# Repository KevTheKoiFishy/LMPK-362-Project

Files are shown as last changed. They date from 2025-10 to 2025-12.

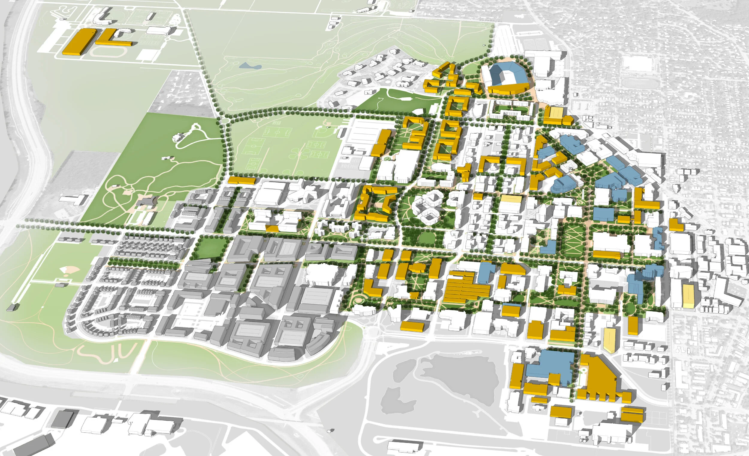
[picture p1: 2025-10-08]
media/images/Purdue_Map.jpg

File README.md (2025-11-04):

# LPMK ECE 362 Final Project
#### GPS Timekeeping and Alarm with Music on RP2350

### Parts List
- RP2350 Proton Board and Debugger
- <span style="color: #777">~~DS Series RTC (I<sup>2</sup>C)~~ (Rejected)</span>
- NEO-6M GPS Module (UART) for Satellite Timekeeping
- LCD TFT Display (SPI) with SD Card Reader (SPI) for Image Storage/Display + Audio Storage
- External DAC (I2C or Custom Build with Shift-Reg) for Audio Playback
- Passive Button Array Keypad for Navigation

### Functions
- Current Time
- GPS Map
- Alarm Settings
- Stopwatch
- Timer

### Project Tasks
1. Define Objectives
    - Get GTA approval
    - Agree on design
    - Assign roles
    - Who should keep the design?
    - Agree on meeting / build times
2. High-level planning
    - Hardware Diagram
    - Software Interface Diagram
3. Detailed Hardware Design
    - Determine pin allocation via GPIO needs
    - Determine required bus speeds via part datasheets
    - Design custom peripherals (ie. DAC)
4. Hardware Prototype
    - Breadboard Build
    - Electrical Verification
5. Software Build
    - Hardware Peripheral Backends
        - Create high-level functions for controlling peripherals easily (like in `display.c`)
        - A way to communicate with frontend
    - Application Frontend
        - Interface and Transition Logic
        - Graphics and UX Design
6. Iterate and Debug
7. PCB Build (if time available)
8. Report / Presentations

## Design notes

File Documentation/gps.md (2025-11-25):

Sample Boot Sequence
```
$GPTXT,01,01,02,MA=CASIC*27
$GPTXT,01,01,02,HW=ATGM332D,0009111648291*12
$GPTXT,01,01,02,IC=AT6558-5N-71-0C510800,J9K11CL-A4-013062*26
$GPTXT,01,01,02,SW=URANUS5,V5.2.1.0*1D
$GPTXT,01,01,02,TB=2019-08-12,10:01:41*4E
$GPTXT,01,01,02,MO=GBR*25
$GPTXT,01,01,02,BS=SOC_BootLoader,V6.2.0.2*34
$GPTXT,01,01,02,FI=00EF4014*7D
```

Sample 1s Push, No Satellites in view
```
$GNGGA,,,,,,0,00,25.5,,,,,,*64
$GNGLL,,,,,,V,M*79
$GPGSA,A,1,,,,,,,,,,,,,25.5,25.5,25.5*02
$BDGSA,A,1,,,,,,,,,,,,,25.5,25.5,25.5*13
$GLGSA,A,1,,,,,,,,,,,,,25.5,25.5,25.5*1E
$GPGSV,1,1,00*79
$BDGSV,1,1,00*68
$GLGSV,1,1,00*65
$GNRMC,,V,,,,,,,,,,M*4E
$GNVTG,,,,,,,,,M*2D
$GNZDA,,,,,,*56
$GPTXT,01,01,01,ANTENNA OK*35
```

Sample push, few satellites in view, only time available
```
$GNGGA,224452.000,,,,,0,00,25.5,,,,,,*7D
$GNGLL,,,,,224452.000,V,M*60
$GPGSA,A,1,,,,,,,,,,,,,25.5,25.5,25.5*02
$BDGSA,A,1,,,,,,,,,,,,,25.5,25.5,25.5*13
$GLGSA,A,1,,,,,,,,,,,,,25.5,25.5,25.5*1E
$GPGSV,1,1,04,13,,,27,17,,,32,19,,,24,22,,,31*71
$BDGSV,1,1,00*68
$GLGSV,1,1,00*65
$GNRMC,224452.000,V,,,,,,,,,,M*57
$GNVTG,,,,,,,,,M*2D
$GNZDA,224452.000,,,,,*4F
$GPTXT,01,01,01,ANTENNA OK*35
```

Sample push, many satellites in view, date and time available
```
$GNGGA,062157.000,,,,,0,00,4.5,,,,,,*4E
$GNGLL,,,,,062157.000,V,N*63
$GPGSA,A,1,,,,,,,,,,,,,7.0,4.5,5.3*30
$BDGSA,A,1,,,,,,,,,,,,,7.0,4.5,5.3*21
$GLGSA,A,1,,,,,,,,,,,,,7.0,4.5,5.3*2C
$GPGSV,3,1,09,05,83,243,,06,08,086,,12,21,206,16,13,21,148,*76
$GPGSV,3,2,09,18,05,278,,20,60,045,,21,61,050,,25,29,243,19*75
$GPGSV,3,3,09,29,52,309,23*47
$BDGSV,1,1,01,34,72,329,*53
$GLGSV,1,1,03,66,47,158,,65,57,065,,88,53,068,*53
$GNRMC,062157.000,V,,,,,,,251125,,,N*54
$GNVTG,,,,,,,,,N*2E
$GNZDA,062157.000,25,11,2025,00,00*4D
$GPTXT,01,01,01,ANTENNA OK*35
```

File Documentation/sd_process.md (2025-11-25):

After over 20 hours of this I finally made… basically a very crude iPod! In case anyone else needs help getting this to work, I want to leave some notes about what worked and what didn’t. The actual implementation and design choices are up to you!

## Setup
### Audio Output Choice

For starters, my approach is using PWM to play audio. This is because if I drive one pin when the wave is positive and another when the wave is negative, with the duty cycles proportional to abs(wave), then I can input those two PWMs to an H-bridge and double the RMS voltage… four times the audio power!

Back To The Future (Opening Guitar Amp Scene) - COMPLETE SOUND REPLACEMENT on Make a GIF

In hindsight, it would have made much more sense to use a DAC… but whatever, I’ve already sent the PCB in. 🤷🏻‍♀️

### File Format Choice

Now I had to choose the file format: **WAV or MP3?** The trade off is WAVs need higher memory bandwidth for their lossless playback, but MP3s need more compute for decoding. As long as `memory-copy time + decoding time < sampling period`, **it really don’t matter.**

HOWEVER. After looking into how to decode MP3s (`Huffman decoding -> inverse cosine transform -> multiply-accumulate`) I thought I should start with WAV for debuggability and sanity reasons. I ended up getting a **memcpy time : playback time** of only 1/8 at 32 KSPS, and this is pretty good.

I chose to use WAV formats with 16 bit-depth, mono channel, and PCM encoding. This just means that after the file header, the audio samples are stored sequentially as little-endian signed `int16_t`s. For each sample, I

1.  get the sample rate from the file header,
2.  set the pwm period to as close as `1 / sample_rate` as possible,
3.  and then update the pwm period to the next sample on each wrap (Lab 5 ts).

For a 44.1kHz audio, the standard sample rate, this means the prescaler is 1 and the top is `(3401 - 1)`. This also means I scale my `[-32768, 32767]` audio sample by `3401.0 / 32767.0` (0 - 100% duty) for each side of the H-bridge. While it’s an 8x reduction in actual precision, it’s only 3 of the 16 bits, which means the precision loss you hear only reduces by 20%.

> _In general_, for any rate exceeding `floor(F_CLK / (1 << bit_depth))`, increasing sample rate reduces bit depth. (This value sits at `2,288` samp/sec for `int16_t`) **This is the main disadvantage of the PWM approach VS a DAC + Class D amp, which achieves the same result with some noise.**



You can use \[online converters\] (https://www.freeconvert.com/mp3-to-wav) to change the bitrate, bit depth, etc. to fit your hardware constraints. I found that my setup works well at **32kHz, 16bit, mono**. After that, it tends to trip over itself - ie. there’s a small chance the memcpy doesn’t complete before the PWM ISR needs it, aka a buffer overrun.

### SPI clock speed

This one really tripped me up. You’d think that with a sample rate of 44.1 Khz, you’d need on the order of `8 bits / byte * 2 bytes / samp * 44.1e3 samp / sec`, so 1Mhz would cut it. However, this kept leading to buffer overruns, and I had to get it to 20Mhz to work. If anyone knows why, please enlighten me!

## Problems and Solutions
Development was not linear, I am but writing it so for presentability.

0. **CLOCK SPEED |** At first I could not get the sd card above 400kHz. I fixed this by writing 32 empty bytes with MOSI == HIGH after `sd_io_high_speed()` is called in `diskio.c` / `disk_initialize`. I just called `sdcard_init_clock();` 16 times. I’m also not sure why this works, but after adding it, I was able to get F\_sck all the way to 30Mhz.

<table><tbody><tr><td></td><td></td></tr></tbody></table>  
Yuhhh.
<br><br>

1. **AUDIO BUFFER |** The first thing I learned was that copying one sample at a time was slow; there’s overhead from going through calls stacks, loops, and accessing the file. When reading like this, the audio playback hardly kept up. I may not have perfect pitch, but it sounded worse than the piano next to WALC on a rainy day.  
On the other hand, reading chunks of 512-1024 bytes takes much less time per byte. So, instead of reading one sample from the file on each pwm-update-isr call, I created a circular FIFO buffer, tracking a read and write index. I raised a flag  in the ISR every time my buffer was 75% empty, and a function running in the main loop cleared the flag before filling it up. 

2. **COPY SIZE |** _HOWEVER_ beyond 1024 bytes at a time, I got hardware errors from FatFS, after which the SD card became inaccessible. If I wanted to consume more than 1024 bytes, I’d `f_read` multiple times, passing in an offset of the buffer each time.

3. **MULTICORE |** This is great, but now the SD read operation takes a good fraction of the buffer-playback time. So what? Well, that means the pwm-updating ISR will often interrupt the memcpy operation!  
SD cards are spoiled and become total princesses when it comes to timing, so this isn’t really ideal. (I’d often get glitches in audio when the memcpy operation gets thrown off).  
Besides, I wanted the main function to be busy doing other things, like – I don’t know – _rendering an entire display?!_ So I moved the poll-buffer-and-memcpy function to core 1, which got rid of most of the glitching.

4. **BUFFER SIZE |** I just tuned this one experimentally; 4096 and 8192 worked well. If you expect delays in reading from the SD, ie. from long wiring, give it more breathing space.

5. **DOUBLE BUFFERING |** Having the circular FIFO wasn't working really well, since the interrupt has to do a bunch of pointer math to figure out where to start and end copying, when to wrap around, etc. Which is DELAY. BAD. BOOO 👻.  
Therefore, I made a read (playback) buffer and write (memcpy) buffer, each 8192 in length (What was that? Oh, don't worry, the RP2350 has 512KB of space!) Now the memcpy function just has to fill up the write buffer from start to end, no wrap-arounds needed.
    - **The setup:**
        - Still have the PWM ISR read samples from the buffer and wrap around to 0 when it reaches the end.
        - Change the memcpy function to `0 -> buff_size` instead of `write index -> read index`.
        - Initialize a Buffer A, a Buffer B, a pointer to the read buffer, and a pointer to the write buffer. Assign one pointer to buffer A and the other to buffer B.
        - Initialize the memcpy flag to true.
        - Have the PWM ISR set the memcpy flag when the read index is at 0 rather than 75% of the way. Also, when read index is 0, swap the read and write buffer pointers.
    - **The process:**
        1. The memcpy flag is initialized to `true`, so as soon as the audio file opens and the `audio_file_open` flag is set, core1 fills the write buffer.
        2. When the read index reaches zero, the read and write buffers are swapped and the memcpy flag is set. Core0 plays what was initially written by Core1, while Core1 prepares the next buffer for Core0.
        3. The process repeats until the song is over, ie. when the file-offset pointer `&audio_file -> fptr` exceeds the filesize, which can be found in the WAV file header or by running `f_size(&audio_file)`.
<br><br>
6. **HARDWARE IMPROVEMENTS |** Even after all that, I was getting periodic glitching. I wasn't able to pinpoint what wasn't being copied using the debugger, and it would only happen sporadically. I thought the long wires between Pi and Display module might be the culprit, so I soldered the pins of a TF-to-SD adapter to short jumper wires and used that instead of the display SD slot. No problems so far.

## Results
Here's a before and after.
<table>
<tr>
<td> Before <b>(VOLUME WARNING)</b> </td> <td> During </td> <td> After </td>
</tr>
<tr>
<td>
<video height="300" controls>
  <source src="/redirect/s3?bucket=uploads&amp;prefix=paste%2Flj4sq92apfjja%2Fbab594b9123cea66a9ada61378599e2250a0d67be978048ed859affb52cb81f0%2FIMG_3299.mp4" type="video/mp4">
</video>
</td>
<td>
<video height="300" controls>
  <source src="/redirect/s3?bucket=uploads&amp;prefix=paste%2Flj4sq92apfjja%2Fdf9a8fb0222346a54379998bff99a8366d6ca67caed4ef2266eb1e69799ea6d2%2FIMG_3327.mp4" type="video/mp4">
</video>
</td>
<td>
<video height="300" controls>
  <source src="/redirect/s3?bucket=uploads&amp;prefix=paste%2Flj4sq92apfjja%2Fa9b92adaf7f5c627dd0be54747a4194046cf4a748687be5e299638a4c2cb165d%2FIMG_3387.mp4" type="video/mp4">
</video>
</td>
</tr>
</table>
<br>
I hope this helps.

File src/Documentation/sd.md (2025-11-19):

# SD Card

## Uses
- Storing and retreiving images, like for map or graphics
- Storing and retreiving audio, like for alarm
- Storing and retreiving user configurations, like alarm settings

## Hardware Interface
Using SPI, connections are as follows:

| SD Pin | Pi Pico 2 Pin |
|:-:|:-:|
| VDD (4) | 3.3V |
| VSS (6) | GND |
| CLK (5) | SCK |
| CS (2) | CS |
| DI (3) | MOSI |
| DO (7) | MISO |

## Software Interface
- SD Card's Partition 0 (FAT32) is mounted as a drive.
- You can then access the SD Card Data using fatFS files in C.

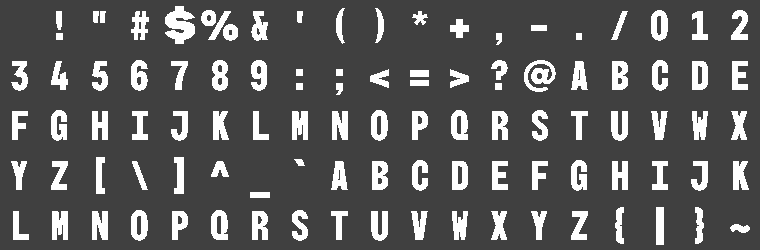
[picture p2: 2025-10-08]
media/fonts/BBH Sans Bogle.png

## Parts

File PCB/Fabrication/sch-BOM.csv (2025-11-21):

Comment | Designator | Footprint | LCSC
100nF | C2,C3,C4,C5 | Capacitor_SMD:C_0201_0603Metric_Pad0.64x0.40mm | C14663
1N4148W | D1,D2 | Diode_SMD:D_SOD-123 | C917030
PROTON_CONN_LEFT | J1 | Connector_PinSocket_2.54mm:PinSocket_1x28_P2.54mm_Vertical
PROTON_CONN_RIGHT | J2 | Connector_PinSocket_2.54mm:PinSocket_1x28_P2.54mm_Vertical
KEYPAD_CONN | J3 | Connector_PinSocket_2.54mm:PinSocket_1x08_P2.54mm_Vertical
TFT_CONN | J4 | Connector_PinSocket_2.54mm:PinSocket_1x09_P2.54mm_Vertical
SD_CONN | J5 | Connector_PinSocket_2.54mm:PinSocket_1x05_P2.54mm_Vertical
GPS_CONN | J6 | Connector_PinSocket_2.54mm:PinSocket_1x04_P2.54mm_Vertical
DEBUG_CONN_L | J7 | Connector_PinSocket_2.54mm:PinSocket_1x03_P2.54mm_Vertical
DEBUG_CONN_R | J8 | Connector_PinSocket_2.54mm:PinSocket_1x04_P2.54mm_Vertical
MMBT3904 | Q1,Q2,Q5,Q6 | Package_TO_SOT_SMD:SOT-23 | C81464
MMBT3906 | Q3,Q4,Q7 | Package_TO_SOT_SMD:SOT-23 | C53444
1k | R1,R2,R3,R4,R5,R6,R7,R8 | Resistor_SMD:R_0201_0603Metric_Pad0.64x0.40mm | C2907002
470 | R14,R15,R16,R17 | Resistor_SMD:R_0201_0603Metric_Pad0.64x0.40mm | C23179
2k2 | R18,R19,R21,R22 | Resistor_SMD:R_0201_0603Metric_Pad0.64x0.40mm | C2907117
510 | R20 | Resistor_SMD:R_0201_0603Metric_Pad0.64x0.40mm | C2907048
33k | R24 | Resistor_SMD:R_0201_0603Metric_Pad0.64x0.40mm | C2907028
10k | R9,R10,R11,R12,R13 | Resistor_SMD:R_0201_0603Metric_Pad0.64x0.40mm | C2906982

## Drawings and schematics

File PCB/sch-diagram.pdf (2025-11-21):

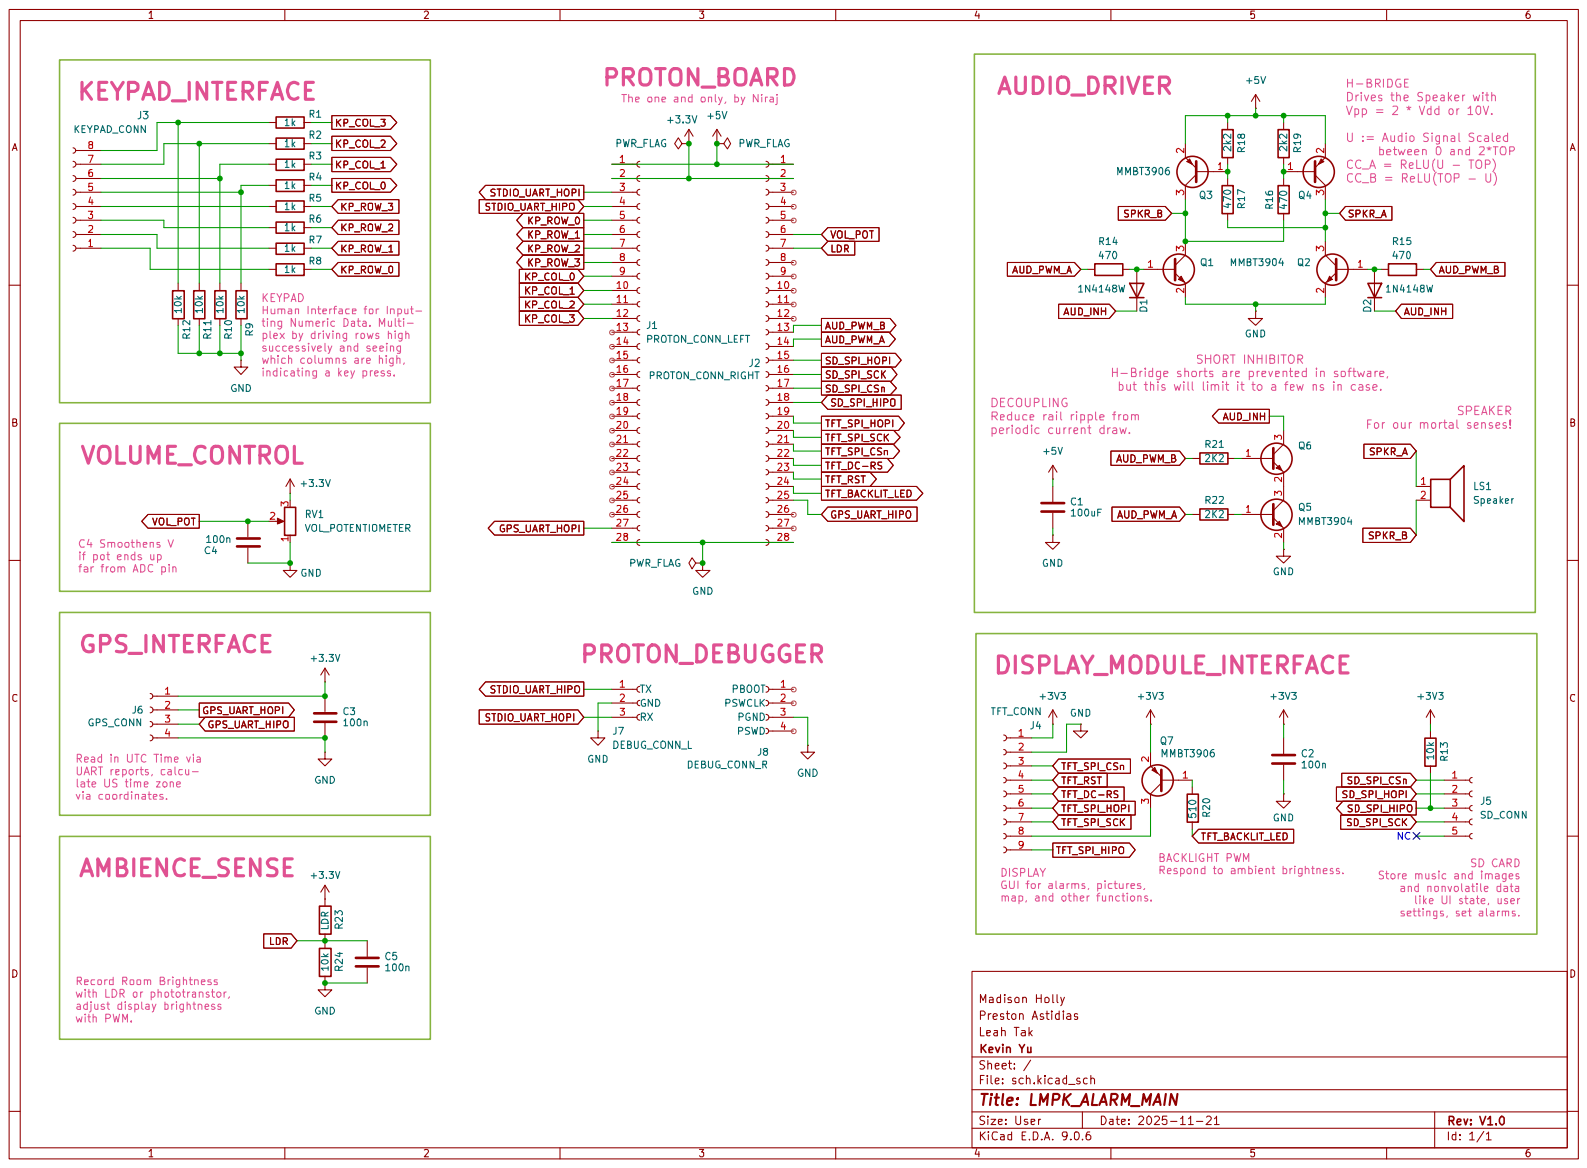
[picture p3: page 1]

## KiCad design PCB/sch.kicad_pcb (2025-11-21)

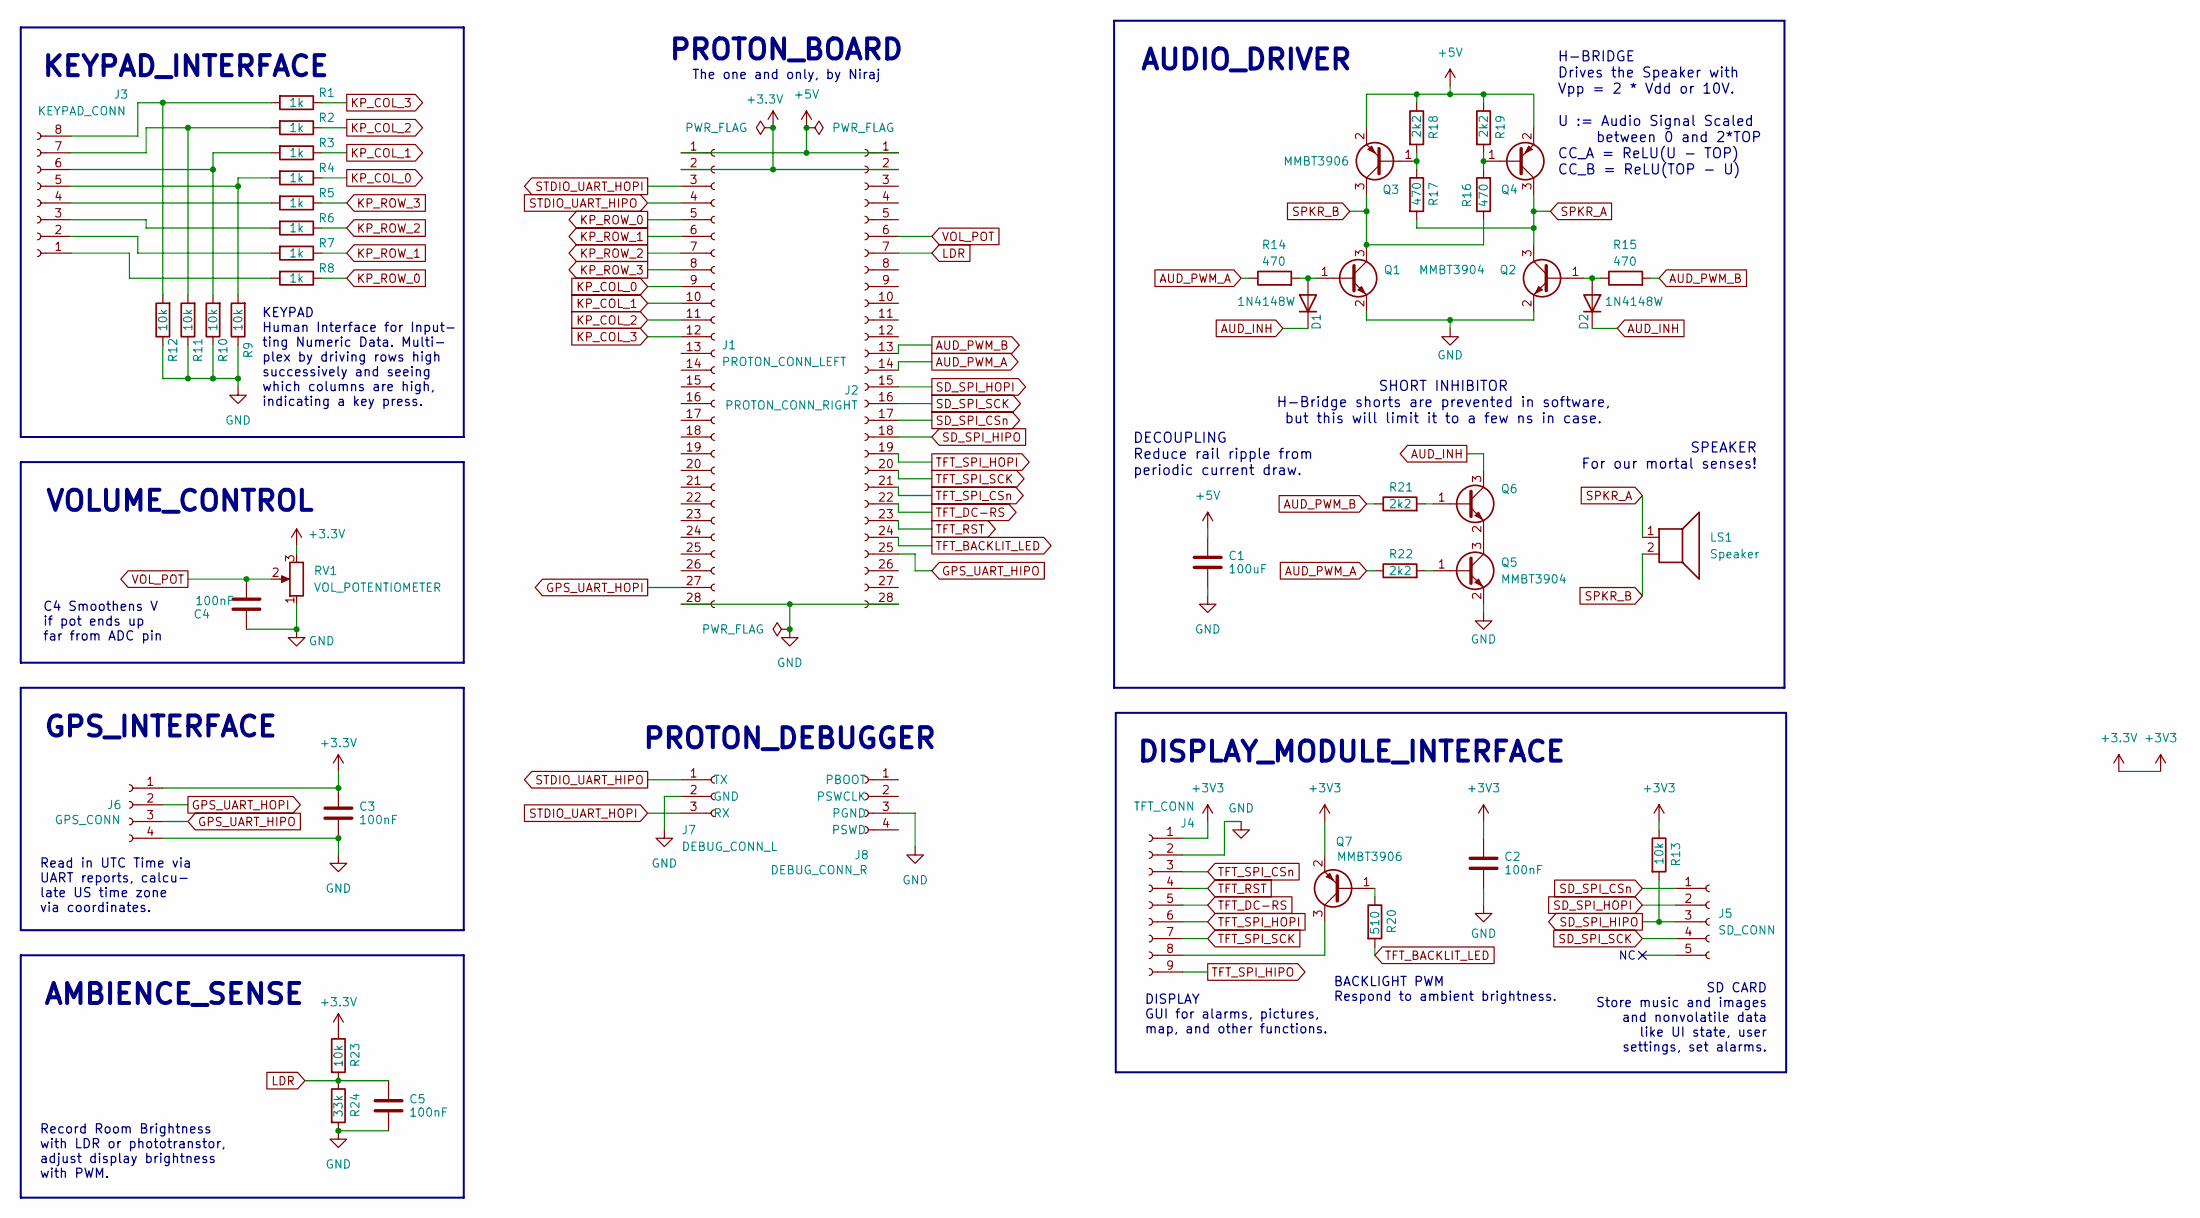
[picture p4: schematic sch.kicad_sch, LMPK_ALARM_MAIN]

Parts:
C1: 100uF; CP_Radial_D8.0mm_P2.50mm; LCSC C109392
C2, C3, C4, C5: 100nF; C_0201_0603Metric_Pad0.64x0.40mm; LCSC C14663
D1, D2: 1N4148W; D_SOD-123; LCSC C917030
J1: PROTON_CONN_LEFT; PinSocket_1x28_P2.54mm_Vertical
J2: PROTON_CONN_RIGHT; PinSocket_1x28_P2.54mm_Vertical
J3: KEYPAD_CONN; PinSocket_1x08_P2.54mm_Vertical
J4: TFT_CONN; PinSocket_1x09_P2.54mm_Vertical
J5: SD_CONN; PinSocket_1x05_P2.54mm_Vertical
J6: GPS_CONN; PinSocket_1x04_P2.54mm_Vertical
J7: DEBUG_CONN_L; PinSocket_1x03_P2.54mm_Vertical
J8: DEBUG_CONN_R; PinSocket_1x04_P2.54mm_Vertical
LS1: Speaker; CONN_2PIN_SCREW
Q1, Q2, Q5, Q6: MMBT3904; SOT-23; LCSC C81464
Q3, Q4, Q7: MMBT3906; SOT-23; LCSC C53444
R1, R2, R3, R4, R5, R6, R7, R8: 1k; R_0201_0603Metric_Pad0.64x0.40mm; LCSC C2907002
R9, R10, R11, R12, R13: 10k; R_0201_0603Metric_Pad0.64x0.40mm; LCSC C2906982
R14, R15, R16, R17: 470; R_0201_0603Metric_Pad0.64x0.40mm; LCSC C23179
R18, R19, R21, R22: 2k2; R_0201_0603Metric_Pad0.64x0.40mm; LCSC C2907117
R20: 510; R_0201_0603Metric_Pad0.64x0.40mm; LCSC C2907048
R23: 10k; R_LDR_5.1x4.3mm_P3.4mm_Vertical; LCSC C125629
R24: 33k; R_0201_0603Metric_Pad0.64x0.40mm; LCSC C2907028
RV1: VOL_POTENTIOMETER; CONN_3PIN_SCREW

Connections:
+3.3V: C2.1, C3.1, J1.2, J2.2, J4.1, J6.1, Q7.2 (E), R13.1, R23.1, RV1.3
+5V: C1.1, J1.1, J2.1, Q3.2 (E), Q4.2 (E), R18.1, R19.1
AUD_INH: D1.1 (K), D2.1 (K), Q6.3 (C)
AUD_PWM_A: J2.14, R14.1, R22.1
AUD_PWM_B: J2.13, R15.2, R21.1
GND: C1.2, C2.2, C3.2, C4.1, C5.2, J1.28, J2.28, J4.2, J6.4, J7.2 (GND), J8.3 (PGND), Q1.2 (E), Q2.2 (E), Q5.2 (E), R9.1, R10.1, R11.1, R12.1, R24.2, RV1.1
GPS_UART_HIPO: J2.25, J6.3
GPS_UART_HOPI: J1.27, J6.2
KP_COL_0: J1.9, R4.1
KP_COL_1: J1.10, R3.1
KP_COL_2: J1.11, R2.1
KP_COL_3: J1.12, R1.1
KP_ROW_0: J1.5, R8.1
KP_ROW_1: J1.6, R7.1
KP_ROW_2: J1.7, R6.1
KP_ROW_3: J1.8, R5.1
LDR: C5.1, J2.7, R23.2, R24.1
unnamed: D1.2 (A), Q1.1 (B), R14.2
unnamed: D2.2 (A), Q2.1 (B), R15.1
unnamed: J3.1, R8.2
unnamed: J3.2, R7.2
unnamed: J3.3, R6.2
unnamed: J3.4, R5.2
unnamed: J3.5, R4.2, R9.2
unnamed: J3.6, R3.2, R10.2
unnamed: J3.7, R2.2, R11.2
unnamed: J3.8, R1.2, R12.2
unnamed: J4.8, Q7.3 (C)
unnamed: Q3.1 (B), R17.1, R18.2
unnamed: Q4.1 (B), R16.2, R19.2
unnamed: Q5.1 (B), R22.2
unnamed: Q5.3 (C), Q6.2 (E)
unnamed: Q6.1 (B), R21.2
unnamed: Q7.1 (B), R20.1
SD_SPI_CSn: J2.17, J5.1
SD_SPI_HIPO: J2.18, J5.3, R13.2
SD_SPI_HOPI: J2.15, J5.2
SD_SPI_SCK: J2.16, J5.4
SPKR_A: LS1.1, Q2.3 (C), Q4.3 (C), R17.2
SPKR_B: LS1.2, Q1.3 (C), Q3.3 (C), R16.1
STDIO_UART_HIPO: J1.4, J7.1 (TX)
STDIO_UART_HOPI: J1.3, J7.3 (RX)
TFT_BACKLIT_LED: J2.24, R20.2
TFT_DC-RS: J2.22, J4.5
TFT_RST: J2.23, J4.4
TFT_SPI_CSn: J2.21, J4.3
TFT_SPI_HIPO: J4.9
TFT_SPI_HOPI: J2.19, J4.6
TFT_SPI_SCK: J2.20, J4.7
VOL_POT: C4.2, J2.6, RV1.2

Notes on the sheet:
C4 Smoothens V if pot ends up far from ADC pin
The one and only, by Niraj
BACKLIGHT PWM Respond to ambient brightness.
AMBIENCE_SENSE
KEYPAD_INTERFACE
DISPLAY_MODULE_INTERFACE
VOLUME_CONTROL
H-BRIDGE Drives the Speaker with Vpp = 2 * Vdd or 10V. U := Audio Signal Scaled between 0 and 2*TOP CC_A = ReLU(U - TOP) CC_B = ReLU(TOP - U)
PROTON_DEBUGGER
KEYPAD Human Interface for Input- ting Numeric Data. Multi- plex by driving rows high successively and seeing which columns are high, indicating a key press.
SHORT INHIBITOR H-Bridge shorts are prevented in software, but this will limit it to a few ns in case.
DISPLAY GUI for alarms, pictures, map, and other functions.
AUDIO_DRIVER
GPS_INTERFACE
Read in UTC Time via UART reports, calcu- late US time zone via coordinates.
SD CARD Store music and images and nonvolatile data like UI state, user settings, set alarms.
PROTON_BOARD
DECOUPLING Reduce rail ripple from periodic current draw.
Record Room Brightness with LDR or phototranstor, adjust display brightness with PWM.
SPEAKER For our mortal senses!

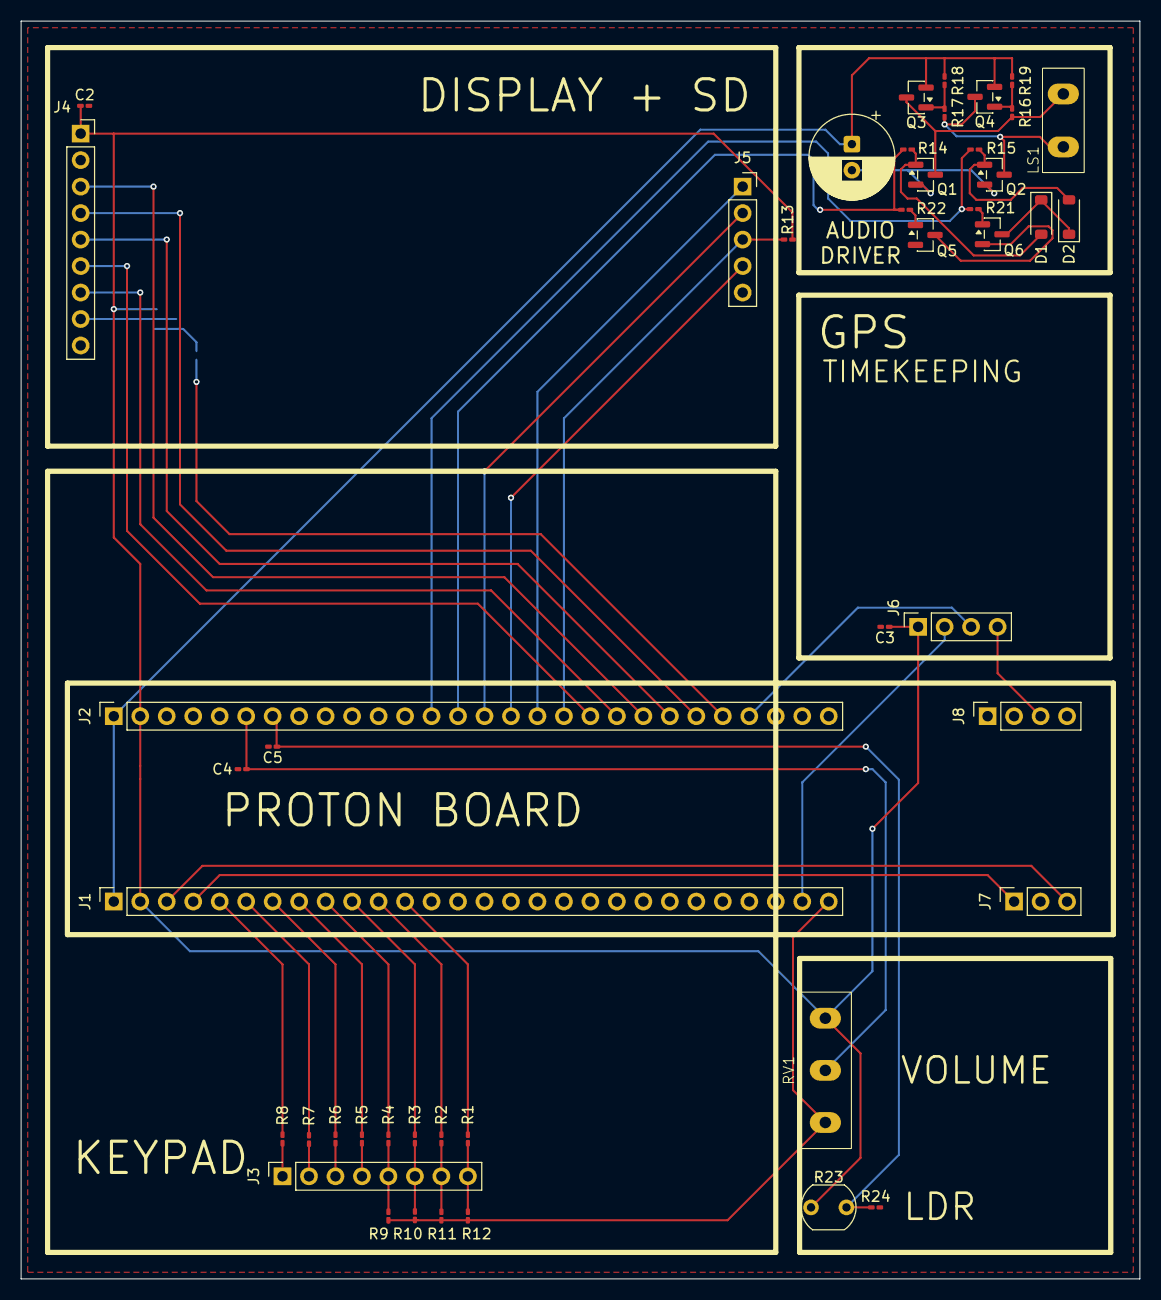
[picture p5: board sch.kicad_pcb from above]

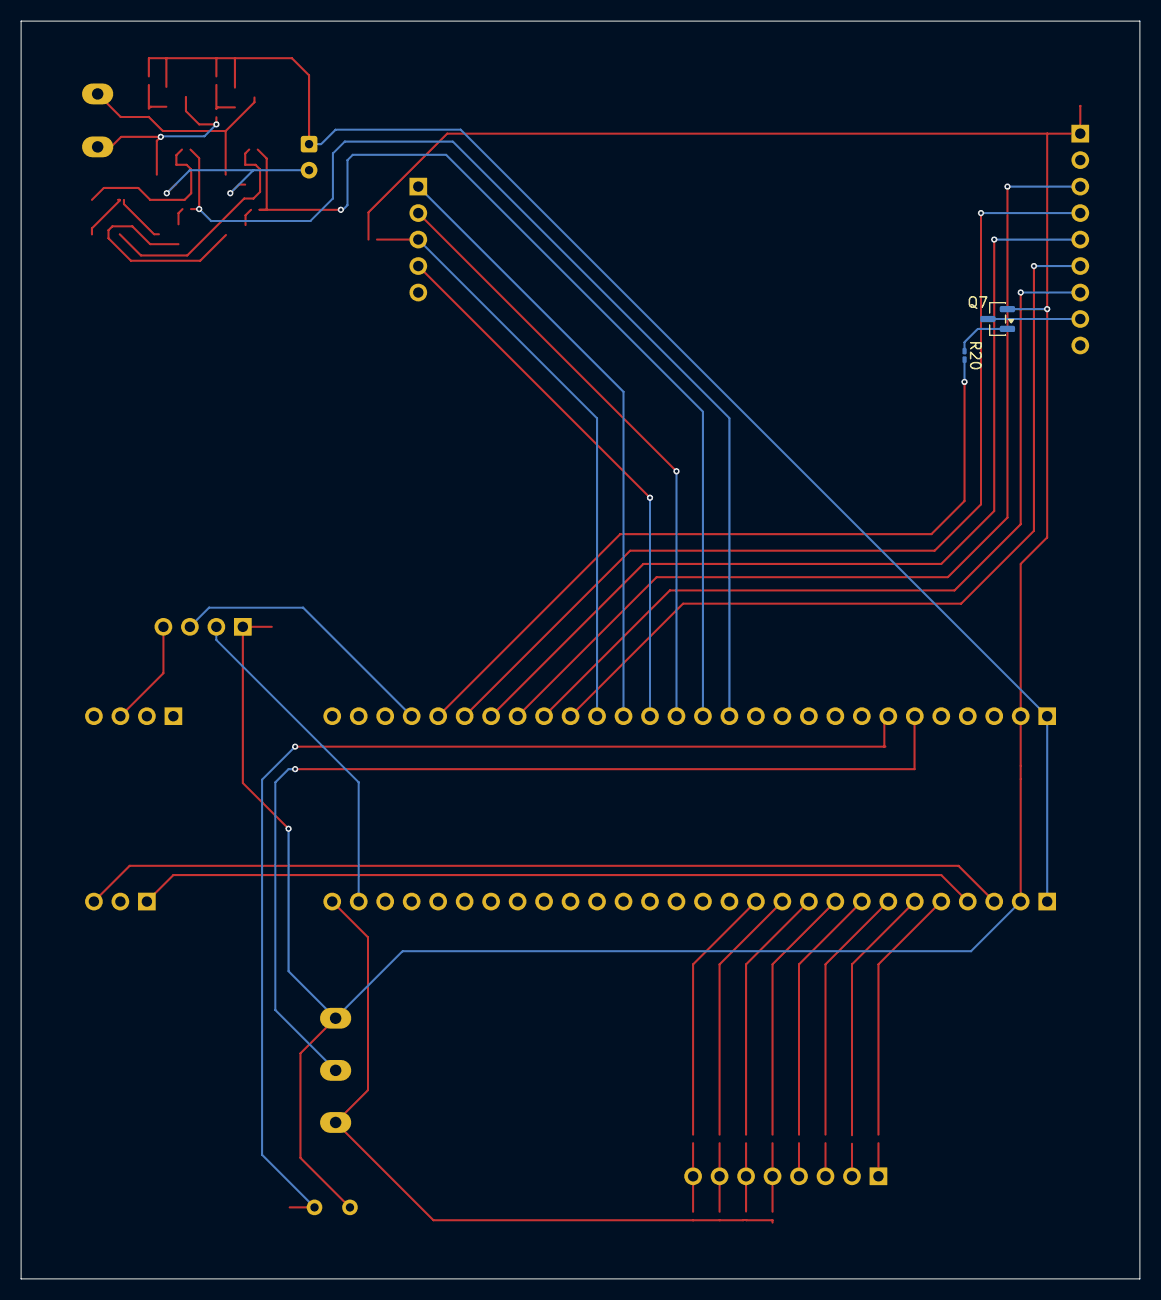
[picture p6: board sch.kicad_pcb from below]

Board: 2 copper layers, 107.3 x 120.7 mm, 48 parts (2 on the bottom side), 49 nets.

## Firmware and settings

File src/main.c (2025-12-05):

#include <stdio.h>
#include "pico/stdlib.h"
#include "pico/multicore.h"

#include "const.h"

#include "sd.h"
#include "sd_sdcard.h"
#include "sd_uart.h"
#include "sd_audio.h"

#include "time.h"
#include "gps_uart.h"
#include "gps_time.h"

#include "ambience_control.h"

#include "tft_display.h"
#include "tft_chardisp.h"
#include "tft_main.h"

#include "keypad_queue.h"
#include "keypad.h"

// #define TEST_SD_CMD
// #define TEST_SD_READ_RATE
// #define TEST_SD_AUDIO_PLAYBACK
// #define TEST_GPS_TIME
#define TEST_AMB_UPDATE
#define TEST_LOCAL_TIME
// #define TEST_KEYPAD
// #define TEST_TFT_MAIN

void core_1_main() {
    core1_loop:
        core1_maintain_audio_buff_routine();
    goto core1_loop;
}

int main() {

    #ifdef TEST_TFT_MAIN
        return tft_main();
    #endif

    // SETUP AND INTERRUPTS HERE
    init_uart();

    printf("\r\n\r\n");
    printf("Booting.");
    
    /////////////////
    // MULTICORE!  //
    /////////////////
    stdio_init_all(); // Enable multicore
    multicore_launch_core1(&core_1_main);
    printf("\n[OK] Core 1: Main Launched");

    /////////////////
    // SD CARD     //
    /////////////////
    init_uart_irq();
    init_sdcard_io();
    printf("\n[OK] SDCard: IO Started");

    /////////////////
    // SD-AUDIO    //
    /////////////////
    mount(0, NULL);
    printf("\n[OK] SDCard: Mounted Volume 0");

    /////////////////
    // VOL, BRIGHT //
    /////////////////
    init_buttons();
    init_buttons_irq();
    printf("\n[OK] Buttons: Int Set");

    init_ambience_adc_and_dma();
    printf("\n[OK] Knob, LDR: ADC, DMA Started");
    
    init_volume_ramp_int();
    printf("\n[OK] Volume Ramp: Int Set");

    display_brightness_configure();
    printf("\n[OK] Display Backlit: Int Set");

    /////////////////
    // KEYPAD      //
    /////////////////
    keypad_init_pins();
    keypad_init_timer();
    printf("\n[OK] Keypad: Pins, Timer started");

    /////////////////
    // GPS-UART    //
    /////////////////
    init_gps_uart(); // GPS time updates automatically!!
    printf("\n[OK] GPS-UART: Sream parse routine started");

    /////////////////
    // TIME        //
    /////////////////
    config_time_update_int();
    printf("\n[OK] Time: Update Int Set");

    /////////////////
    // DISPLAY     //
    /////////////////
    tft_init_pins();
    tft_init();
    cd_clear();
    printf("\n[OK] TFT Display: Initialized");

    #ifdef TEST_SD_CMD
        sd_command_shell(); // uncomment for debug
    #endif
    
    #ifdef TEST_SD_READ_RATE
        open_sd_audio_file(DEFAULT_AUDIO_PATH);
        audio_file_result buff_load_result = 0;
        uint32_t pos_0 = get_data_offset();
        uint32_t tick  = time_us_32();

        uint16_t i = 1000;
        while(!buff_load_result && --i){
            buff_load_result = fill_audio_buffer();
        }

        uint32_t tock     = time_us_32();
        uint32_t pos_f    = get_data_offset();
        float    byterate = 1000000.0 * (pos_f - pos_0) / (tock - tick);
        printf("Average Read Byte Rate: %lu bytes over %lu us = %.2f bytes/sec", pos_f - pos_0, tock - tick, byterate);
    #endif

    #ifdef TEST_SD_AUDIO_PLAYBACK
        open_sd_audio_file(DEFAULT_AUDIO_PATH);
        configure_audio_play();
        start_audio_playback();
    #endif

    // TIME VARIABLES
    my_time_t    utc_time      ;
    my_date_t    utc_date      ;
    my_time_t    local_std_time;
    my_date_t    local_std_date;
    my_time_t    local_dst_time;
    my_date_t    local_dst_date;
    my_time_t    local_time    ;
    my_date_t    local_date    ;
    my_alarm_t   alarm_cfg     ;
    gps_status_t gps_status    ;

    core0_loop:
        utc_time          =   get_utc_time();
        utc_date          =   get_utc_date();
        local_std_time    =   get_local_std_time();
        local_std_date    =   get_local_std_date();
        local_dst_time    =   get_local_dst_time();
        local_dst_date    =   get_local_dst_date();
        local_time        =   get_local_time();
        local_date        =   get_local_date();
        alarm_cfg         =   get_alarm_cfg();
        gps_status        =   gps_get_status();

        alarm_fire_routine();
        cd_update(
            local_time.hours,
            local_time.minutes,
            local_time.seconds,
            gps_status != CONNECTING,
            alarm_cfg.hours,
            alarm_cfg.minutes,
            alarm_cfg.enabled,
            is_audio_playing()
        );
        sleep_ms(1000);

        #ifdef TEST_AMB_UPDATE
            printf("\n");
            printf("\nKnob Mode  | %s", get_knob_mode() == BRIGHTNESS_MODE ? "BRIGHTNESS" : "VOLUME");
            printf("\nVolume     | Ramp:  %s, Setting: %4d, Scalar: %6.3f",       get_volume_ramp_en()      ? "T" : "F", get_volume_setting(), get_volume_scalar());
            printf("\nBrightness | Adapt: %s, Setting: %4d, LDR:    %6d, Value: %6d"  ,  get_brightness_adapt_en() ? "T" : "F", get_brightness_setting(), get_brightness_env(), (uint16_t)get_brightness_valf());
        #endif

        #ifdef TEST_GPS_TIME
            sleep_ms(1000);
            printf("\nGPS Time: "); printf(gps_get_timestr()); printf("\n\n");
        #endif

        #ifdef TEST_LOCAL_TIME
            printf("\n--- Local Time Info ---");
            printf("\n  GPS Status     | %s", gps_get_status() == GOT_DATETIME ? "GOT DATETIME" : gps_get_status() == GOT_TIME ? "GOT TIME" : gps_get_status() == CONNECTING ? "CONNECTING" : "UNKNOWN");

            printf("\n  UTC Time       | %02d:%02d:%02d %04d-%02d-%02d", utc_time.hours, utc_time.minutes, utc_time.seconds, utc_date.year, utc_date.month, utc_date.day);
            printf("\n  Local STD Time | %02d:%02d:%02d %04d-%02d-%02d", local_std_time.hours, local_std_time.minutes, local_std_time.seconds, local_std_date.year, local_std_date.month, local_std_date.day);
            printf("\n  Local DST Time | %02d:%02d:%02d %04d-%02d-%02d", local_dst_time.hours, local_dst_time.minutes, local_dst_time.seconds, local_dst_date.year, local_dst_date.month, local_dst_date.day);
            printf("\n  Local Time     | %02d:%02d:%02d %04d-%02d-%02d", local_time.hours, local_time.minutes, local_time.seconds, local_date.year, local_date.month, local_date.day);
            printf("\n  Alarm Config   | %02d:%02d:00, %s %s", alarm_cfg.hours, alarm_cfg.minutes, alarm_cfg.enabled ? "ENABLED" : "DISABLED", alarm_cfg.fire ? "FIRING" : "");
            printf("\n-----------------------\n");
        #endif

        #ifdef TEST_KEYPAD
            uint16_t keyevent = key_pop();

            if (keyevent == (uint16_t)-1) {
                printf("\nKEV: No Key Event\n");
            }
            else {
                if (keyevent & (1 << 8))
                    printf("\nKEV: Pressed  %c\n", (char) (keyevent & 0xFF));
                else if (keyevent != 0)
                    printf("\nKEV: Released %c\n", (char) (keyevent & 0xFF));
            }
        #endif

    goto core0_loop;
    
}

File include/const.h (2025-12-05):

// Constants and macros to make our lives easier!

// In order to prevent pin and hardware peripheral conflicts
// between different parts of the project, state your pin choices
// and spi/pwm/adc channels here.

// For brevity, only put stuff that you're "claiming" for your functions.
// Put all other define statements in your specific header files!

#include <hardware/spi.h>
#include <hardware/timer.h>
#include <hardware/uart.h>

// MACROS
#define GET_CORE_NUM()      *(uint32_t *) (SIO_BASE + SIO_CPUID_OFFSET)
#define ADC_WAIT()          while ( !(adc_hw -> cs & ADC_CS_READY_BITS) )
#define UART_WAIT()         while (!uart_is_writable(uart0)) { tight_loop_contents(); }
#define GPS_UART_WAIT()     while (!uart_is_writable(uart1)) { tight_loop_contents(); }

/*** FORMAT                         ***/
/*** FUNCTIONALITY - resources used ***/

// ONBOARD - sio
#define ONBOARD_LEDS        {22, 23, 24, 25}
#define BRIGHT_PUSHB_PIN    21
#define VOL_PUSHB_PIN       26

// KEYPAD - sio
#define NUM_PAD_PINS        8
#define KEYPAD_IO           {2, 3, 4, 5, 6, 7, 8, 9}
#define KEYPAD_MASK         (0b11111111u << 2u)
#define KEYPAD_ROWMASK      (0b00001111u << 2u)
#define KEYPAD_COLMASK      (0b11110000u << 2u)

#define KEYPAD_TIMER_HW     timer0_hw
#define KEYPAD_COLSCAN_ALARM 0
#define KEYPAD_ROWSCAN_ALARM 1

// 7-SEG DISPLAY - unused
#define DISP_7SEG_MASK      (0x7FF << 10u)

// GPS MODULE - uart1
#define GPS_UART_PORT       uart1
#define GPS_UART_IRQ        UART_IRQ_NUM(GPS_UART_PORT)
#define GPS_UART_INT_PRI    2
#define GPS_PIN_TX          24
#define GPS_PIN_RX          25

// LISTEN IDK WHO DAFUQ IS USING TIMER0_IRQ_3 BUT IT'S TAKEN
// EVEN BEFORE MAIN IS CALLED AND WILL GIVE YOU A HARD FAULT
// DO NOT USE ITTTTTT 😡😡😡😡😡😡😡😡😡😡😡😡😡😡😡😡😡😡😡😡

// TIME UPDATES - timer0
#define TIME_STEP_TIMER_HW  timer1_hw
#define TIME_STEP_INT_NUM   TIMER1_IRQ_0
#define TIME_STEP_ALARM     0
#define TIME_STEP_INT_PRI   1

// VOLUME CONTROL - adc4, timer0
#define VOL_RAMP_TIMER_HW   timer1_hw
#define VOL_RAMP_INT_NUM    TIMER1_IRQ_1
#define VOL_RAMP_TIM_ALARM  1
#define VOL_RAMP_INT_PRI    3
#define KNOB_ADC_PIN        45
#define AMB_DMA_CH          0

// DISPLAY (Maddie) - sio, spi1
#define TFT_SPI             spi1
#define TFT_PIN_SCK         30

#define TFT_PIN_MOSI        31
#define TFT_PIN_CS          29
#define TFT_PIN_DC          28
#define TFT_PIN_RST         27

// DISPLAY BRIGHTNESS (Leah, Kevin) - pwm8a, adc4

#define TFT_BACKLIT_INT_NUM PWM_IRQ_WRAP_1
#define TFT_BACKLIT_INT_PRI 2
#define TFT_BACKLIT_SLICE   3
#define TFT_BACKLIT_PIN     23
#define TFT_BACKLIT_CH      (TFT_BACKLIT_PIN & 1)

#define LDR_ADC_PIN         44
#define LDR_DMA_CH          1

// SD CARD - spi0
#define SD_SPI_PORT         spi0
#define SD_PIN_MISO         32
#define SD_PIN_CS           33
#define SD_PIN_SCK          34
#define SD_PIN_MOSI         35

// PWM AUDIO PLAYBACK - pwm10ab, pwm_irq_wrap_1
#define BASE_CLK            150000000u
#define AUDIO_PWM_INT_NUM   PWM_IRQ_WRAP_0
#define AUDIO_PWM_INT_PRI   0
#define AUDIO_PWM_SLICE     11
#define AUDIO_PWM_PIN_L     38
#define AUDIO_PWM_PIN_H     39

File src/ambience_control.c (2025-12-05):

#include "const.h"
#include "arbitration.h"
#include "ambience_control.h"

//// GPIO ////
volatile knobMode knob_mode = BRIGHTNESS_MODE;
knobMode    get_knob_mode() { return knob_mode; }

//// ADC DMA DESTINATION ////
uint16_t adc_outs[ADC_ROUNDROBIN_BUF_LEN] = {4095, 0}; // Knob, LDR

//// VOLUME & VOLUME RAMP ////
dma_channel_hw_t * amb_dma_channel = &dma_hw -> ch[AMB_DMA_CH]; // Will use for BOTH volume and Brightness!

uint16_t *  volume_adc_out     = &adc_outs[0];
uint16_t    prev_volume_adc_out = 4095;
float       volume_scalar      = 1.0f;

uint16_t    volume_ramp_tF     = -1;
uint16_t    volume_ramp_delT   = -1;
float       volume_ramp_r      = -1.0f;
float       volume_ramp_delR   = -1.0f;
float       volume_ramp_a0     = -1.0f;
float       volume_ramp_af     = -1.0f;
bool        volume_ramp_en     = true;

uint16_t    get_volume_setting()    { return knob_mode == VOLUME_MODE ? *volume_adc_out : prev_volume_adc_out; }
float       get_volume_scalar()     { return volume_scalar;  }
bool        get_volume_ramp_en()    { return volume_ramp_en; }

//// BRIGHTNESS ////
dma_channel_hw_t * LDR_dma_ch = &dma_hw -> ch[LDR_DMA_CH];
float       brightness_curr_val         = 0.0f;
uint16_t *  brightness_set_adc_out      = &adc_outs[0];
uint16_t    prev_brightness_set_adc_out = 0;
uint16_t *  brightness_env_adc_out      = &adc_outs[1];
bool        brightness_adapt_en         = true;

uint16_t    get_brightness_setting() { return knob_mode == BRIGHTNESS_MODE ? *brightness_set_adc_out : prev_brightness_set_adc_out; }
uint16_t    get_brightness_env()     { return *brightness_env_adc_out; }
float       get_brightness_valf()    { return brightness_curr_val; }
bool        get_brightness_adapt_en(){ return brightness_adapt_en; }

//// GPIO ////

void init_buttons(void) {
    gpio_set_dir(BRIGHT_PUSHB_PIN, GPIO_IN); // button to control brightness
    gpio_put(BRIGHT_PUSHB_PIN, 0);
    gpio_set_function(BRIGHT_PUSHB_PIN, GPIO_FUNC_SIO);

    gpio_set_dir(VOL_PUSHB_PIN, GPIO_IN); // button to control volume
    gpio_put(VOL_PUSHB_PIN, 0);
    gpio_set_function(VOL_PUSHB_PIN, GPIO_FUNC_SIO);
}

void buttons_isr() {
    // Brightness Button 
    if (gpio_get_irq_event_mask(BRIGHT_PUSHB_PIN) & GPIO_IRQ_EDGE_FALL) {
        gpio_acknowledge_irq(BRIGHT_PUSHB_PIN, GPIO_IRQ_EDGE_FALL);

        // Toggle Adaptive Brightness
        if (knob_mode == BRIGHTNESS_MODE) {
            brightness_adapt_en = !brightness_adapt_en;
        }
        // Set knob to control brightness
        else {
            prev_volume_adc_out = *volume_adc_out;
            knob_mode = BRIGHTNESS_MODE;
        }
    }

    // Volume Button
    if (gpio_get_irq_event_mask(VOL_PUSHB_PIN) & GPIO_IRQ_EDGE_FALL) {   
        gpio_acknowledge_irq(VOL_PUSHB_PIN, GPIO_IRQ_EDGE_FALL);

        // Toggle volume ramping
        if (knob_mode == VOLUME_MODE) {
            volume_ramp_en = !volume_ramp_en;
        }
        // Switch to volume mode
        else {
            prev_brightness_set_adc_out = *brightness_set_adc_out;
            knob_mode = VOLUME_MODE;
        }
    }
}

void init_buttons_irq() {
    // add the handler for both pins at once, enable the GPIO IRQ for both pins and BANK0 IRQ interrupt.
    uint32_t mask = (1u << BRIGHT_PUSHB_PIN) | (1u << VOL_PUSHB_PIN);
    gpio_add_raw_irq_handler_masked(mask, &buttons_isr);

    // configure GP21 and GP26 to a rising edge
    gpio_set_irq_enabled(BRIGHT_PUSHB_PIN, GPIO_IRQ_EDGE_FALL, true);
    gpio_set_irq_enabled(VOL_PUSHB_PIN,    GPIO_IRQ_EDGE_FALL, true);

    // enable the top-level GPIO Bank 0 IRQ line 
    irq_set_enabled(IO_IRQ_BANK0, true);
}

//// ADC CONVERSIONS - KNOB ////

// Start round robin freerunning conversions
static void init_ambience_adc_freerun() {
    // Initialize ADC and Pins
    adc_init();
    adc_gpio_init(KNOB_ADC_PIN);
    adc_gpio_init(LDR_ADC_PIN);

    // Initial Channel = Knob
    adc_select_input(KNOB_ADC_PIN - 40);

    // Enable FIFO, Enable DREQ, DREQ threshold is 1, Disable Err Logging, Disable byte shift
    adc_fifo_setup(true, true, 1, false, false);

    // Take turns converting LDR and Knob
    adc_set_round_robin((1 << (KNOB_ADC_PIN - 40)) | (1 << (LDR_ADC_PIN - 40)));

    // Round Robin Mode
    hw_set_bits(&adc_hw->cs, ADC_CS_START_MANY_BITS);
}

// Initialize volume DMA Channel to trigger each time all sample conversions finish
static void init_ambience_dma() {

    // dma_channel_config_t ctrl_trig_cfg = { .ctrl = 0 };
    // channel_config_set_read_increment(&ctrl_trig_cfg, false);
    // channel_config_set_write_increment(&ctrl_trig_cfg, true);
    // dma_channel_configure(AMB_DMA_CH, &ctrl_trig_cfg, adc_outs, &adc_hw->fifo, ADC_ROUNDROBIN_BUF_LEN, false);

    // return;

    // Configure DMA Channel 0 to read from the ADC FIFO and write to the variable "volume". 
    amb_dma_channel -> read_addr  = (uint32_t) &adc_hw->fifo;
    amb_dma_channel -> write_addr = (uint32_t) &adc_outs;
    
    // Set the transfer count, or TRANS_COUNT, to the arithmetic OR of two values.
    amb_dma_channel -> transfer_count = (0x1 << DMA_CH0_TRANS_COUNT_MODE_LSB) | 1u; // 1 transfers for each DREQ. Do not decrement transfer count.

    // Initialize the control trigger register of the DMA to zero.
    amb_dma_channel -> ctrl_trig = 0;

    // Create a uint32_t variable for control trig
    uint32_t ctrl_trig_val = 0;

    // Halfword (16 bit) Write
    ctrl_trig_val |= (DMA_CH0_CTRL_TRIG_DATA_SIZE_VALUE_SIZE_HALFWORD << DMA_CH0_CTRL_TRIG_DATA_SIZE_LSB);

    // Ring Write
    ctrl_trig_val |= DMA_CH0_CTRL_TRIG_RING_SEL_BITS;                            // Ring write, not read
    ctrl_trig_val |= ADC_ROUNDROBIN_BUF_LEN << DMA_CH0_CTRL_TRIG_RING_SIZE_LSB;  // Ring size of 2
    ctrl_trig_val |= DMA_CH0_CTRL_TRIG_INCR_WRITE_BITS;                          // Increment write address by 2 bytes
 
    // Specify the ADC DREQ signal as the TREQ trigger.
    ctrl_trig_val |= (DREQ_ADC << DMA_CH0_CTRL_TRIG_TREQ_SEL_LSB);
    
    // Set the EN bit
    ctrl_trig_val |= 1u;

    // Write the temp variable to the dma_hw->ch[0].ctrl_trig register.
    amb_dma_channel -> ctrl_trig = ctrl_trig_val;
}

// Initialize automatic conversions and volume_dial update.
void init_ambience_adc_and_dma() {
    // Start dma BEFORE adc so it is ready for every ADC_DREQ
    init_ambience_dma();
    init_ambience_adc_freerun();
}

//// VOLUME MODULATION -- HELPERS ////

// Clamp between [0, 1]
static float clamp_01(float x) {
    if (x < 0.0f)   return 0.0f;
    if (x > 1.0f)   return 1.0f;
    return x;
}

// Clamp between [0, 100]
static float clamp_pct(float x) {
    if (x < 0.0f)   return 0.0f;
    if (x > 100.0f) return 100.0f;
    return x;
}

// Alarm volume ramp-up fxn: Makes the ramp start gentle and increase faster near the end.
static float volume_curve(float x) {
    x = clamp_01(x);
    float k = VOLUME_RAMP_POW_CURVE_EXP;
    return powf(x, k);    // y = x^k
}

//// VOLUME MODULATION -- BLOCKING ////
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

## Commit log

2025-11-04 💾 SD Card SPI functions, Audio Buffer
2025-11-04 🧹 Clean up a bit
2025-11-19 🔉 Class D Speaker Driver Circuit
2025-11-19 💾 SD Card Works!
2025-11-19 🕵🏻‍♀️ SD Parse Audio Headers
2025-11-20 🍪 Decide Pin Assignments
2025-11-20 PCB Started
    [sch.kicad_pcb, sch.kicad_sch]
2025-11-21 SCH Done
    [sch.kicad_pcb, sch.kicad_sch]
2025-11-21 PCB Done
    [sch.kicad_pcb, sch.kicad_sch]
2025-11-21 Amended with LDR, Added Gerbers, BOM, positions
    [sch-BOM.csv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]
2025-11-22 🔊 Audio works but ISR takes longer than its trigger period
2025-11-22 🔊 Slight Improvement by Cutting out Buffer
2025-11-23 🔊 Multicore approach, race condition nightmare 😭😭😭
2025-11-23 🔊 Real time playing, sometimes sd access drops
2025-11-23 🔊 Only minor glitches after replacing write-to-read-ptr with write-entire-buff-when-almost-empty
    [sd_audio.c]
2025-11-23 🔊 Try double buffer, similar issue
    [sd_audio.c]
2025-11-23 🔊 Okay fr this is probably good enough
2025-11-25 🔊 SD Audio Docs
2025-11-25 ⏰ GPS Time Parsing
2025-11-26 🔊 SD Close and Reopen File Works
2025-12-02 🔊 Integrate volume control and sd_audio functions; resolve code errors; temporarily remove 7seg output to reduce runtime
    [ambience_control.c, const.h, main.c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]
2025-12-02 🕹️ control audio and visual
2025-12-03 🔊 Untested Volume Ramp Integration
2025-12-03 📝 ambience_control: Rename for Merging
2025-12-04 🔊 Untested Volume Ramp and Pushbutton Control Integration
2025-12-04 🔊 Untested Adaptive Brightness Control
2025-12-05 🔁 Integrate all except display so far
2025-12-05 😴 TESTED Ambience Control Integration
2025-12-05 😴 TESTED GPS Time and Alarm Fire Integration. TIMER HANDLER CONFLICT NIGHTMARE UGHGHHGHGHGH
2025-12-05 😴 TESTED Display and Keypad Integration
2025-12-05 😴 TESTED Adaptive Brightness Control Integration
